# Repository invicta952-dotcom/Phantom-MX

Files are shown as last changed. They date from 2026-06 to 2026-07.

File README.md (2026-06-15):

# Phantom-MX

##   what is this??
Phantom-mx is cutom made keyboard with 87 mechincal switches, roatary encoder and custom built case and qmk firmware. It has 2 layer of functions to switch between as per your need. the case type is integrated plate mount which mean you dont need to lock the plate with case with 1000's of screw

---
##   why phantom-mx??
you may find many other custom keyboard with more features and better than this, but the one thing you will never find is perfect keyboard which is in budget and also meet your needs perfectly. it was built to meet my needs and also in budget. 
<br>
**bonus point**:- it has some really cool silkscreen

---
##   how to assemble it??
### 1. Ordering the PCB
1. **Download Production Files**: Navigate to the `PCB/` directory in this repository and download the Gerber zip file (e.g., `Gerber_Phantom-MX.zip`). Do not extract it.
2. **Choose a Manufacturer**: Upload the zip file to a PCB fabrication service such as JLCPCB, PCBWay, or OSH Park.
3. **Configure Board Settings**: Use the following standard specifications:
   * **Layers**: 2 Layers
   * **Thickness**: 1.6 mm
   * **Surface Finish**: HASL (or ENIG for better pad durability)
4. **Assembly (Optional)**: If you prefer factory assembly for surface-mount components (diodes/sockets), upload the BOM (Bill of Materials) and CPL (Component Placement List / Centroid file) provided in the repository to their PCBA service.

---

### 3. Hardware Assembly
1. **Solder Diodes**: Always solder small, low-profile components first. solder the diodes before the swithces for easy soldering.
2. **Solder Sockets/Switches**: solder the switches by passing them from top plate and then top layer of pcb.
3. **Mount the Pi Pico**: Place the Pi Pico onto its designated footprint. solder it in backside of the pcb.

---
# Images

#   case
Screenshot From 2026-06-04 00-17-47

---

#   zine
mechincal keyboard

---

#   pcb
Screenshot From 2026-06-04 00-14-03
Screenshot From 2026-05-25 17-31-20
<br>
<br>
<br>
onshape link <br>
https://cad.onshape.com/documents/175f6b23ffbe170e5e8f7975/w/d68c6b2354c565e22789bc76/e/012a72f814c196a96be20986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

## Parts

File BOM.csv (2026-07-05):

Id. | Footprint | Quantity | price | link
1 | DIODE | 88 | $1.50 | https://robu.in/product/1n4148-1w-zener-diode-pack-of-50/
2 | SW_Cherry_MX | 87 | $32.00 | https://neomacro.in/products/cherry-mx2a-linear-switch?variant=49109795701014
5 | RotaryEncoder_Alps_EC11E-Switch_Vertical_H20mm | 1 | $1.00 | https://robu.in/product/hongyan-ec11h-7ce20p1zy20-rotary-encoder-with-push-button-switch-vertical-plug-in-5-pin/
6 | RaspberryPi_Pico | 1 | $4.50 | https://robu.in/product/raspberry-pi-pico/
7 | stablizer | 1 | $10.00 | https://neomacro.in/products/tx-stabilizers-rev-3?variant=47932019474710&country=IN&currency=INR
8 | pcb | 1 | $35.00
9 | soldering iron | 1 | $10.00
10 | keycaps | 1 | $10.00
 |  | total | $105.00

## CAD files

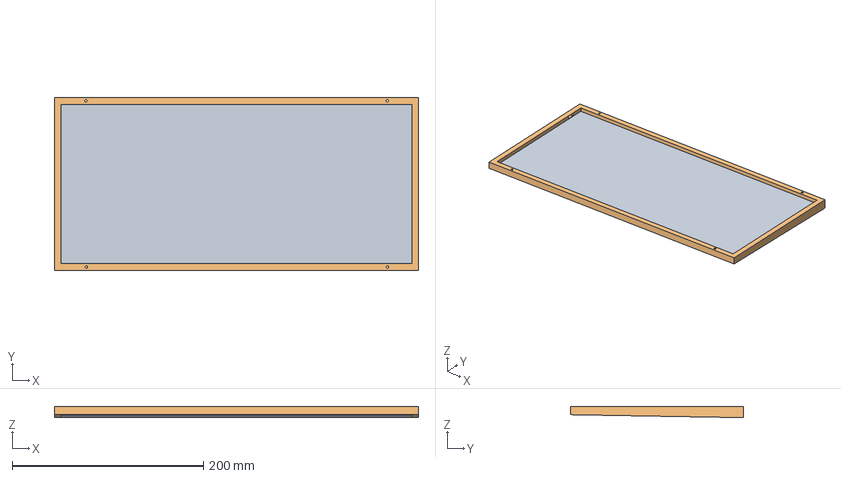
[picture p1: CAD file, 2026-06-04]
CASE/bottom.step
380.9 x 180.7 x 11.7 mm

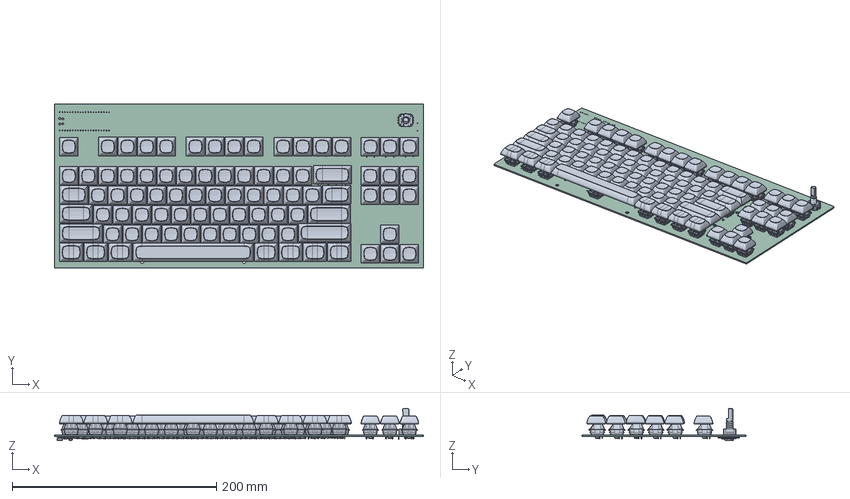
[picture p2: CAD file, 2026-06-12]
PCB/keyborad.step
360.9 x 160.7 x 31.5 mm
MX1A-C1NN--3DModel-STEP-510211 x 87
MX Mount v1 x 72
DSA 1.75u
DSA 1.25u x 7
DSA 2.75u
DSA 2.25u x 2
DSA 1.5u x 2
DSA 2u
DSA Spacebar 6.25u (50mm spacing)
RaspberryPi_Pico_Module_KiCad
keyborad_PCB

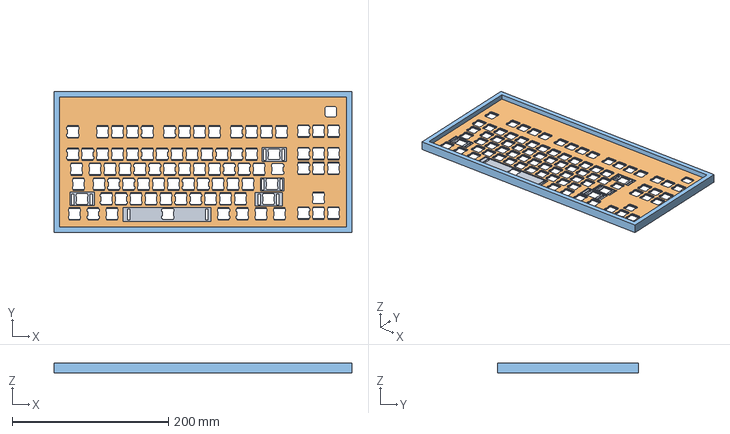
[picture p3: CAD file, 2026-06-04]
CASE/top.step
380.9 x 180.7 x 12.3 mm

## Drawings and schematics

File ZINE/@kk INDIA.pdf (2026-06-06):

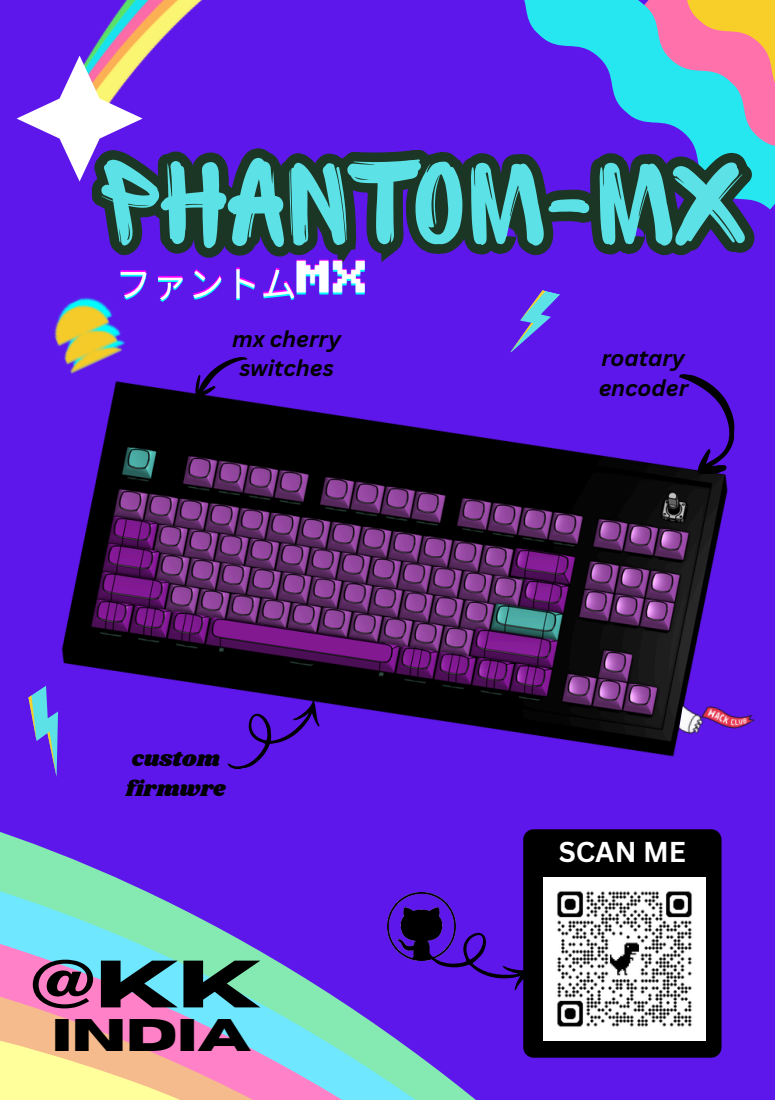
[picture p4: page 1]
@kk INDIA; SCAN ME PPHHAANNTTOOMM--MMXX; roatary encoder; custom firmwre; フファァンントトムムMMXX; mx cherry switches

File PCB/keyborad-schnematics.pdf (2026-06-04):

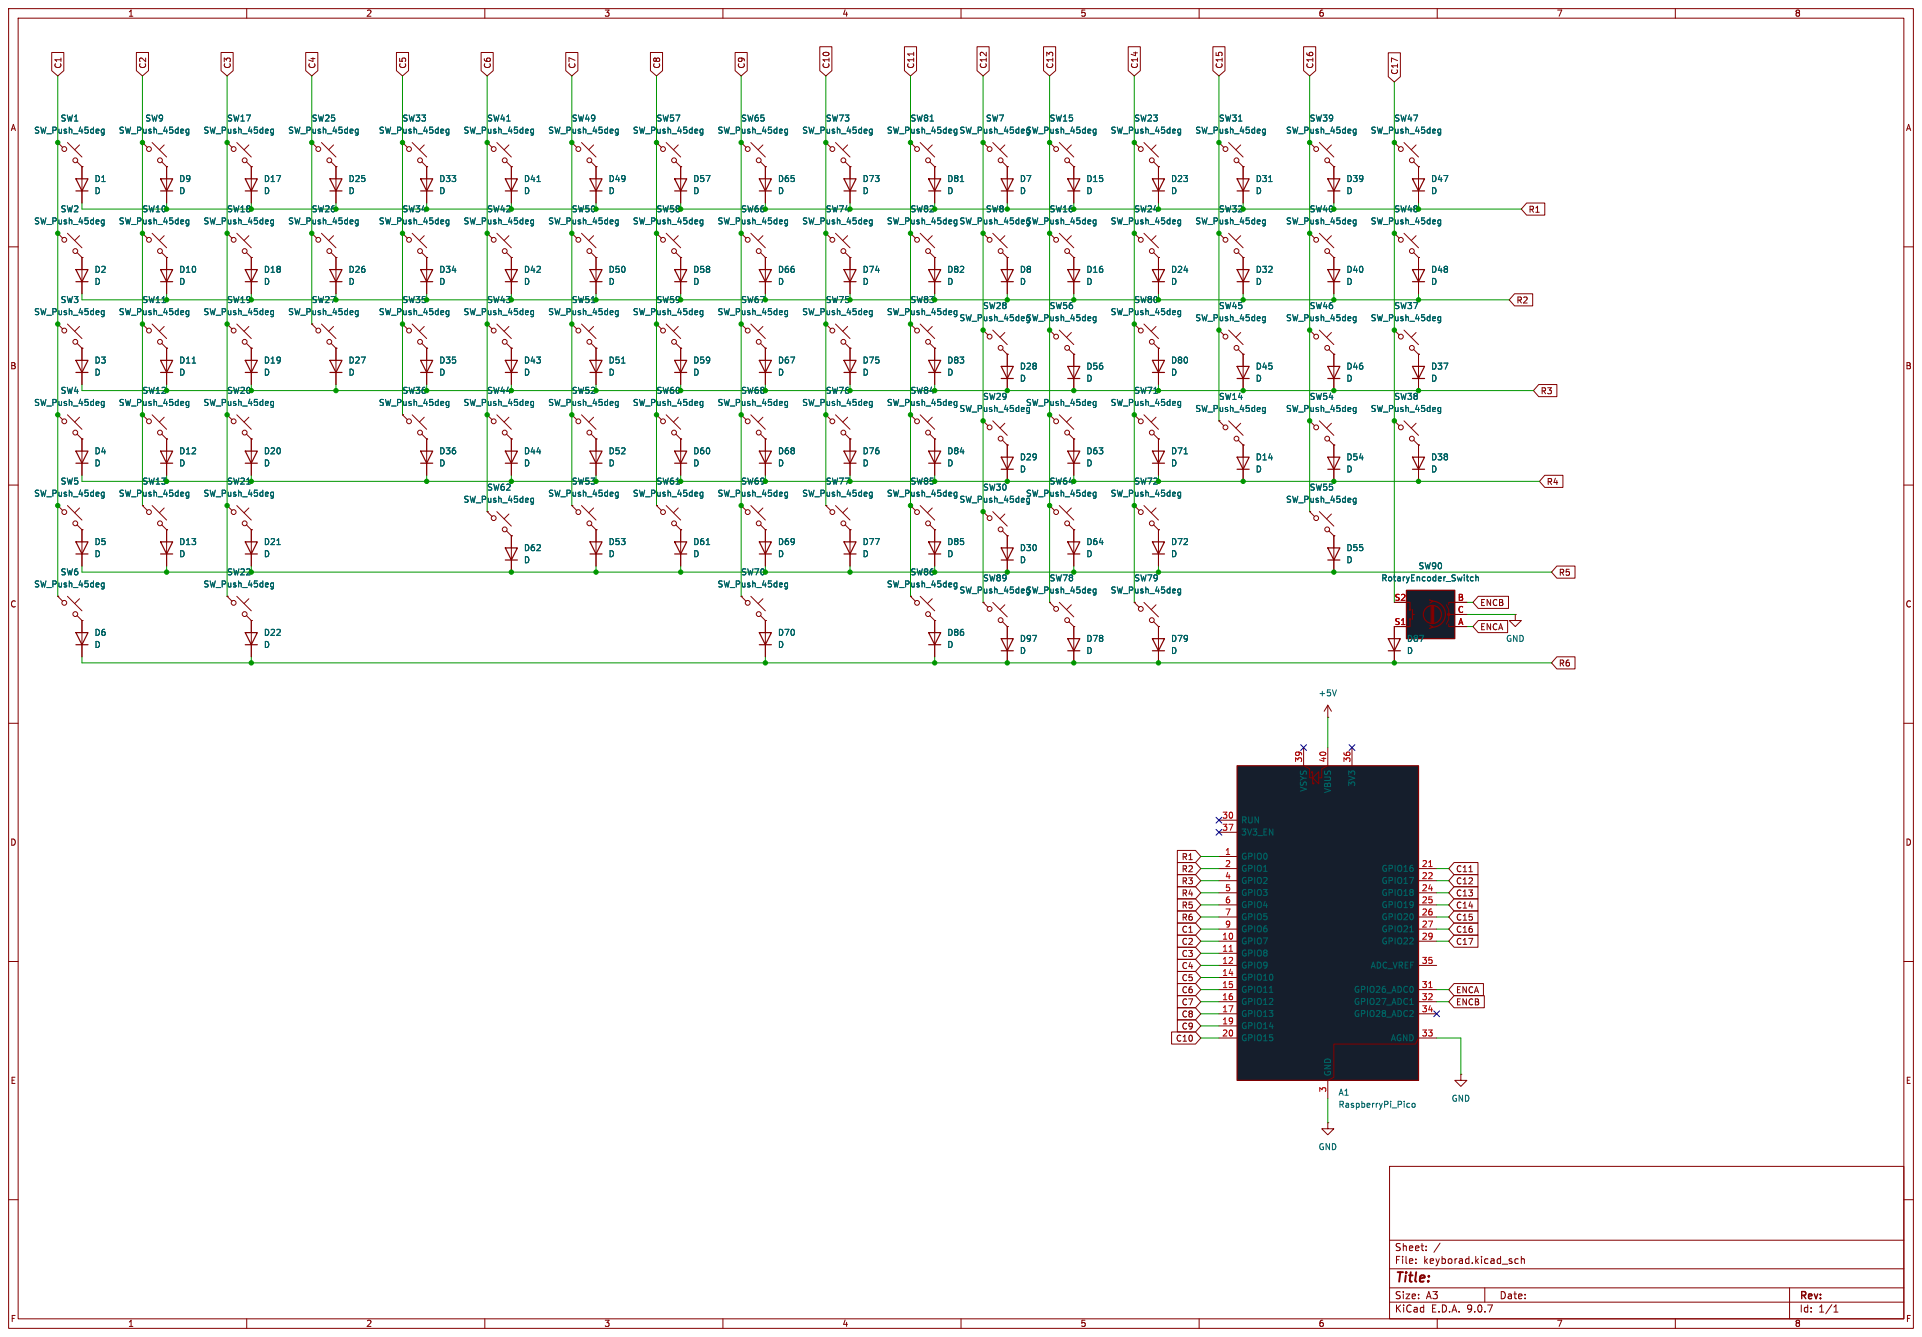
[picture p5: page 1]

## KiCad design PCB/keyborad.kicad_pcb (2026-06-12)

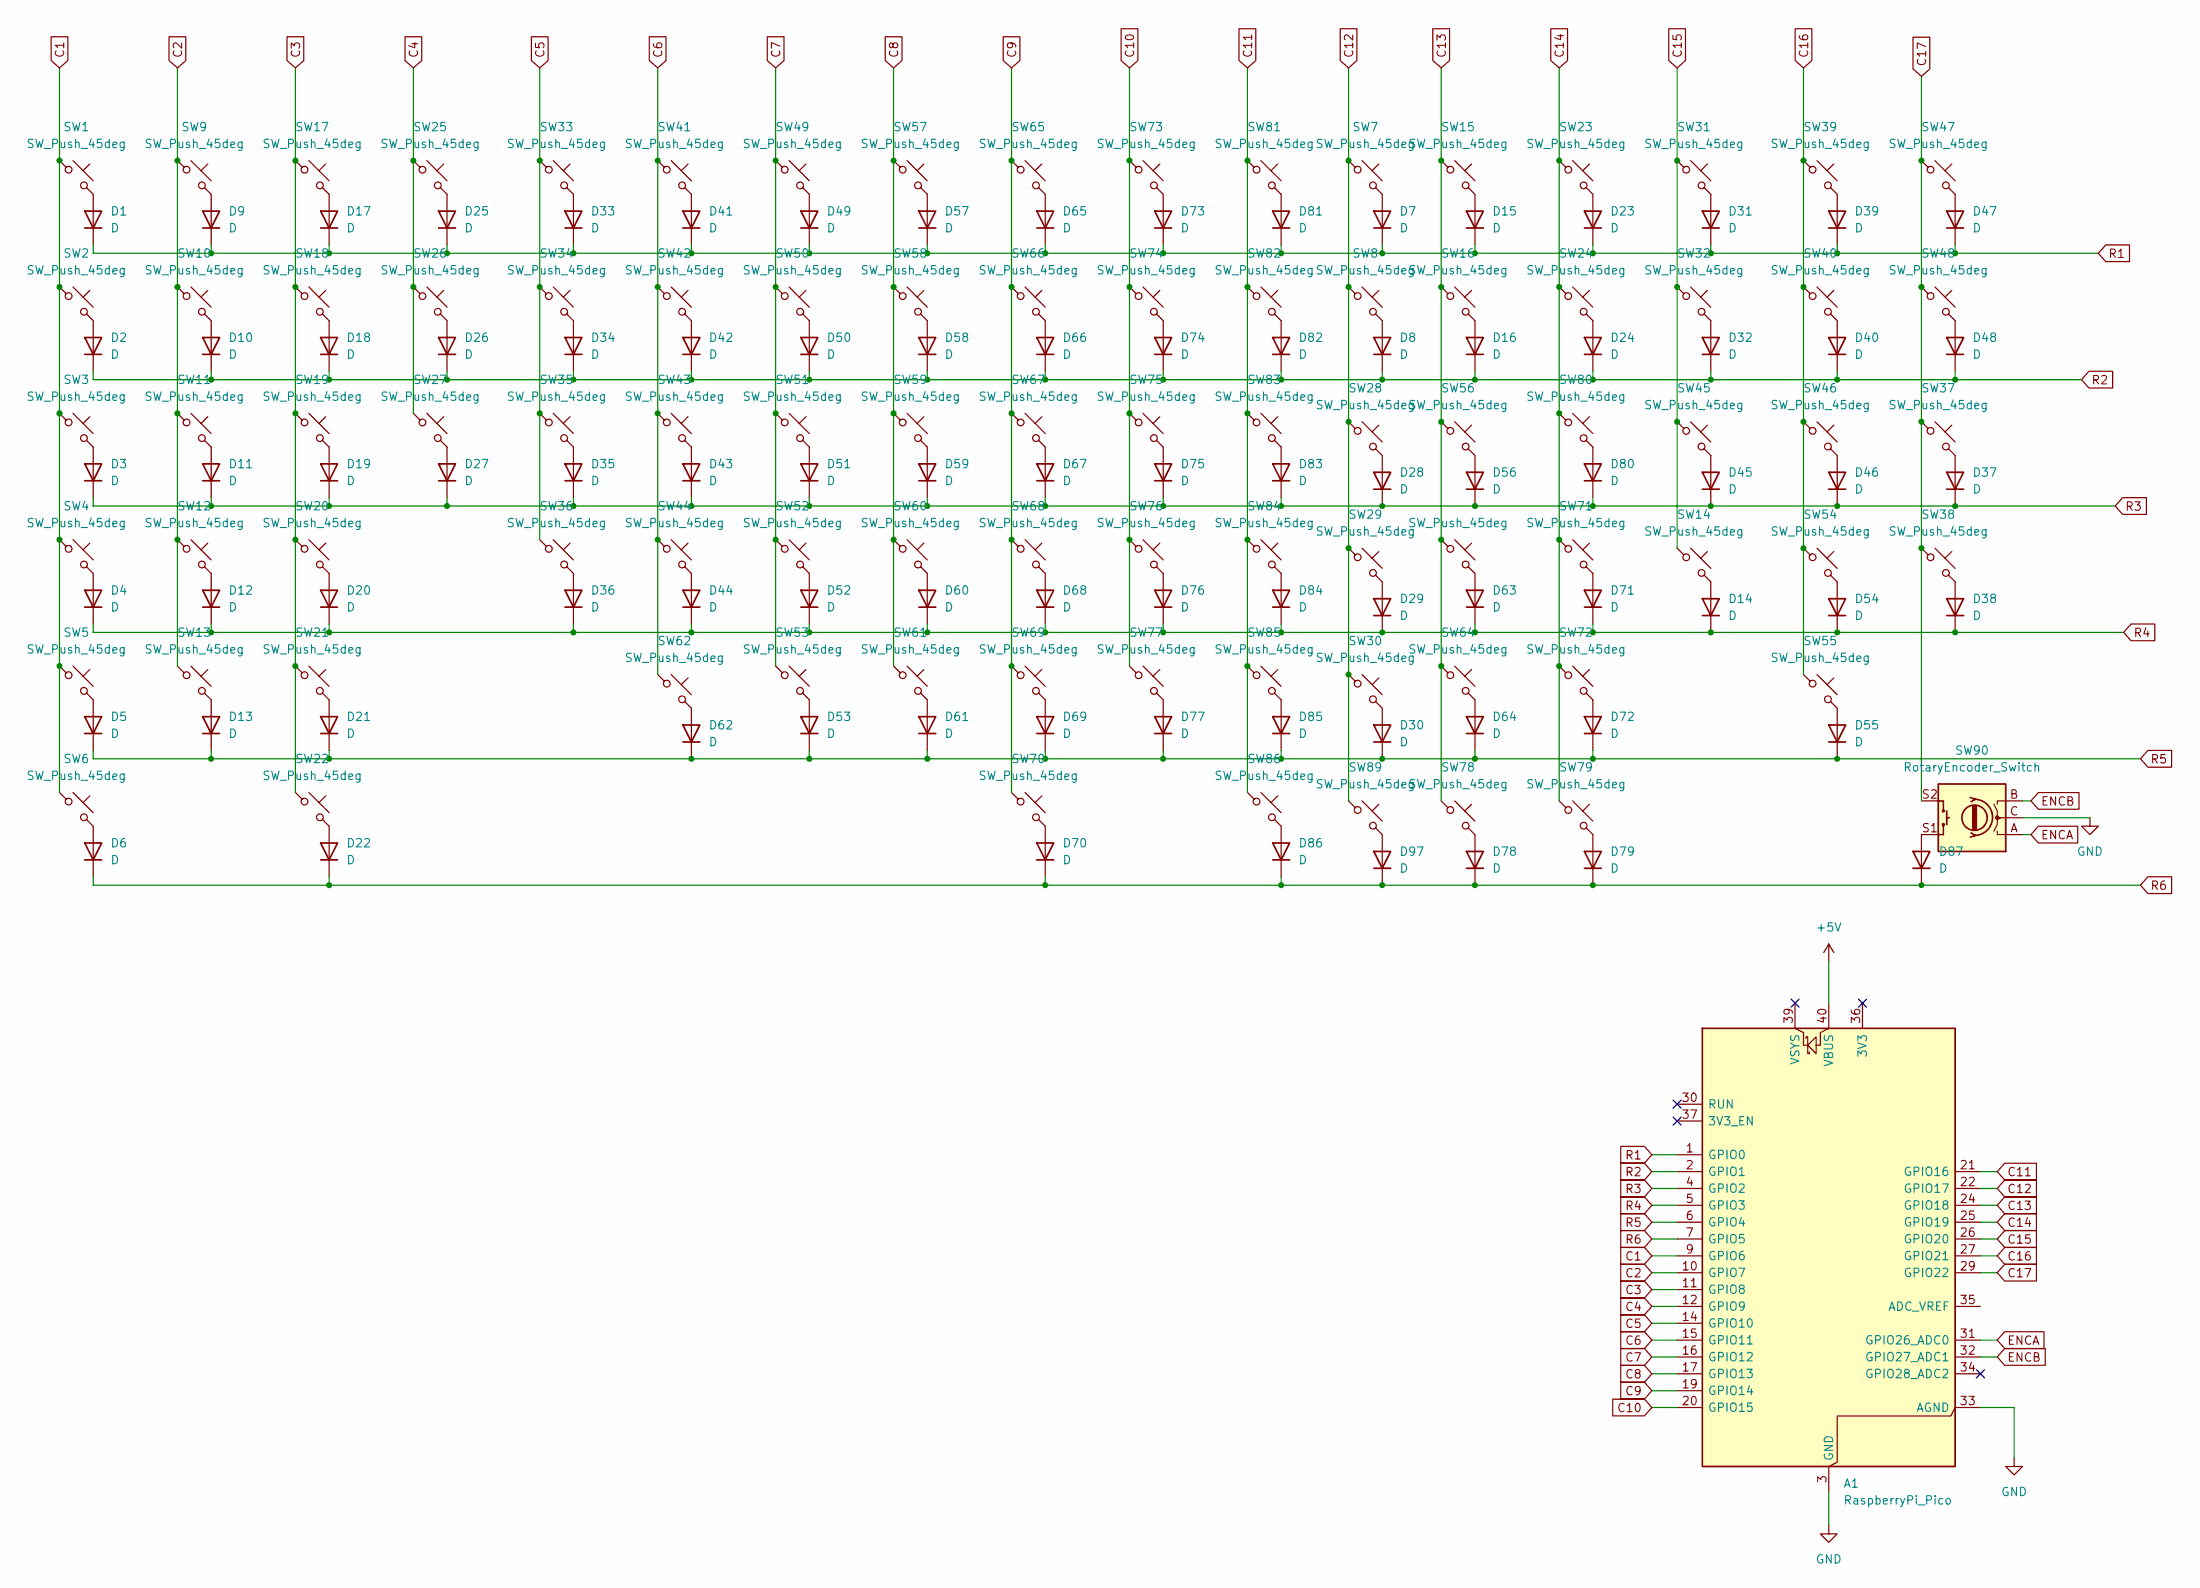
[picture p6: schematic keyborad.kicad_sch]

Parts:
A1: RaspberryPi_Pico; RaspberryPi_Pico_Common_Unspecified
D1, D2, D3, D4, D5, D6, D7, D8, D9, D10, D11, D12, D13, D14, D15, D16, D17, D18, D19, D20, D21, D22, D23, D24, D25, D26, D27, D28, D29, D30, D31, D32, D33, D34, D35, D36, D37, D38, D39, D40, D41, D42, D43, D44, D45, D46, D47, D48, D49, D50, D51, D52, D53, D54, D55, D56, D57, D58, D59, D60, D61, D62, D63, D64, D65, D66, D67, D68, D69, D70, D71, D72, D73, D74, D75, D76, D77, D78, D79, D80, D81, D82, D83, D84, D85, D86, D87, D97: D; DIODE
SW1, SW2, SW7, SW8, SW9, SW10, SW11, SW12, SW14, SW15, SW16, SW17, SW18, SW19, SW20, SW21, SW23, SW25, SW26, SW27, SW28, SW29, SW30, SW31, SW32, SW33, SW34, SW35, SW36, SW37, SW38, SW39, SW40, SW41, SW42, SW43, SW44, SW45, SW46, SW47, SW48, SW49, SW50, SW51, SW52, SW53, SW54, SW55, SW56, SW57, SW58, SW59, SW60, SW61, SW62, SW63, SW64, SW65, SW66, SW67, SW68, SW69, SW73, SW74, SW75, SW76, SW77, SW81, SW82, SW83, SW84, SW85: SW_Push_45deg; SW_Cherry_MX_1.00u_PCB
SW3, SW80: SW_Push_45deg; SW_Cherry_MX_1.50u_PCB
SW4: SW_Push_45deg; SW_Cherry_MX_1.75u_PCB
SW5, SW71: SW_Push_45deg; SW_Cherry_MX_2.25u_PCB
SW6, SW13, SW22, SW78, SW79, SW86, SW89: SW_Push_45deg; SW_Cherry_MX_1.25u_PCB
SW24: SW_Push_45deg; SW_Cherry_MX_2.00u_PCB
SW70: SW_Push_45deg; SW_Cherry_MX_6.25u_PCB
SW72: SW_Push_45deg; SW_Cherry_MX_2.75u_PCB
SW90: RotaryEncoder_Switch; RotaryEncoder_Alps_EC11E-Switch_Vertical_H20mm

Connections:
+5V: A1.40 (VBUS)
C1: A1.9 (GPIO6), SW1.1, SW2.1, SW3.1, SW4.1, SW5.1, SW6.1
C2: A1.10 (GPIO7), SW9.1, SW10.1, SW11.1, SW12.1, SW13.1
C3: A1.11 (GPIO8), SW17.1, SW18.1, SW19.1, SW20.1, SW21.1, SW22.1
C4: A1.12 (GPIO9), SW25.1, SW26.1, SW27.1
C5: A1.14 (GPIO10), SW33.1, SW34.1, SW35.1, SW36.1
C6: A1.15 (GPIO11), SW41.1, SW42.1, SW43.1, SW44.1, SW62.1
C7: A1.16 (GPIO12), SW49.1, SW50.1, SW51.1, SW52.1, SW53.1
C8: A1.17 (GPIO13), SW57.1, SW58.1, SW59.1, SW60.1, SW61.1
C9: A1.19 (GPIO14), SW65.1, SW66.1, SW67.1, SW68.1, SW69.1, SW70.1
C10: A1.20 (GPIO15), SW73.1, SW74.1, SW75.1, SW76.1, SW77.1
C11: A1.21 (GPIO16), SW81.1, SW82.1, SW83.1, SW84.1, SW85.1, SW86.1
C12: A1.22 (GPIO17), SW7.1, SW8.1, SW28.1, SW29.1, SW30.1, SW89.1
C13: A1.24 (GPIO18), SW15.1, SW16.1, SW56.1, SW63.1, SW64.1, SW78.1
C14: A1.25 (GPIO19), SW23.1, SW24.1, SW71.1, SW72.1, SW79.1, SW80.1
C15: A1.26 (GPIO20), SW14.1, SW31.1, SW32.1, SW45.1
C16: A1.27 (GPIO21), SW39.1, SW40.1, SW46.1, SW54.1, SW55.1
C17: A1.29 (GPIO22), SW37.1, SW38.1, SW47.1, SW48.1, SW90.S2
ENCA: A1.31 (GPIO26_ADC0), SW90.A
ENCB: A1.32 (GPIO27_ADC1), SW90.B
GND: A1.3 (GND), A1.8 (GND), A1.13 (GND), A1.18 (GND), A1.23 (GND), A1.28 (GND), A1.33 (AGND), A1.38 (GND), SW90.C
unnamed: D1.2 (A), SW1.2
unnamed: D2.2 (A), SW2.2
unnamed: D3.2 (A), SW3.2
unnamed: D4.2 (A), SW4.2
unnamed: D5.2 (A), SW5.2
unnamed: D6.2 (A), SW6.2
unnamed: D7.2 (A), SW7.2
unnamed: D8.2 (A), SW8.2
unnamed: D9.2 (A), SW9.2
unnamed: D10.2 (A), SW10.2
unnamed: D11.2 (A), SW11.2
unnamed: D12.2 (A), SW12.2
unnamed: D13.2 (A), SW13.2
unnamed: D14.2 (A), SW14.2
unnamed: D15.2 (A), SW15.2
unnamed: D16.2 (A), SW16.2
unnamed: D17.2 (A), SW17.2
unnamed: D18.2 (A), SW18.2
unnamed: D19.2 (A), SW19.2
unnamed: D20.2 (A), SW20.2
unnamed: D21.2 (A), SW21.2
unnamed: D22.2 (A), SW22.2
unnamed: D23.2 (A), SW23.2
unnamed: D24.2 (A), SW24.2
unnamed: D25.2 (A), SW25.2
unnamed: D26.2 (A), SW26.2
unnamed: D27.2 (A), SW27.2
unnamed: D28.2 (A), SW28.2
unnamed: D29.2 (A), SW29.2
unnamed: D30.2 (A), SW30.2
unnamed: D31.2 (A), SW31.2
unnamed: D32.2 (A), SW32.2
unnamed: D33.2 (A), SW33.2
unnamed: D34.2 (A), SW34.2
unnamed: D35.2 (A), SW35.2
unnamed: D36.2 (A), SW36.2
unnamed: D37.2 (A), SW37.2
unnamed: D38.2 (A), SW38.2
unnamed: D39.2 (A), SW39.2
unnamed: D40.2 (A), SW40.2
unnamed: D41.2 (A), SW41.2
unnamed: D42.2 (A), SW42.2
unnamed: D43.2 (A), SW43.2
unnamed: D44.2 (A), SW44.2
unnamed: D45.2 (A), SW45.2
unnamed: D46.2 (A), SW46.2
unnamed: D47.2 (A), SW47.2
unnamed: D48.2 (A), SW48.2
unnamed: D49.2 (A), SW49.2
unnamed: D50.2 (A), SW50.2
unnamed: D51.2 (A), SW51.2
unnamed: D52.2 (A), SW52.2
unnamed: D53.2 (A), SW53.2
unnamed: D54.2 (A), SW54.2
unnamed: D55.2 (A), SW55.2
unnamed: D56.2 (A), SW56.2
unnamed: D57.2 (A), SW57.2
unnamed: D58.2 (A), SW58.2
unnamed: D59.2 (A), SW59.2
unnamed: D60.2 (A), SW60.2
unnamed: D61.2 (A), SW61.2
unnamed: D62.2 (A), SW62.2
unnamed: D63.2 (A), SW63.2
unnamed: D64.2 (A), SW64.2
unnamed: D65.2 (A), SW65.2
unnamed: D66.2 (A), SW66.2
unnamed: D67.2 (A), SW67.2
unnamed: D68.2 (A), SW68.2
unnamed: D69.2 (A), SW69.2
unnamed: D70.2 (A), SW70.2
unnamed: D71.2 (A), SW71.2
unnamed: D72.2 (A), SW72.2
unnamed: D73.2 (A), SW73.2
unnamed: D74.2 (A), SW74.2
unnamed: D75.2 (A), SW75.2
unnamed: D76.2 (A), SW76.2
unnamed: D77.2 (A), SW77.2
unnamed: D78.2 (A), SW78.2
unnamed: D79.2 (A), SW79.2
unnamed: D80.2 (A), SW80.2
unnamed: D81.2 (A), SW81.2
unnamed: D82.2 (A), SW82.2
unnamed: D83.2 (A), SW83.2
unnamed: D84.2 (A), SW84.2
unnamed: D85.2 (A), SW85.2
unnamed: D86.2 (A), SW86.2
unnamed: D87.2 (A), SW90.S1
unnamed: D97.2 (A), SW89.2
R1: A1.1 (GPIO0), D1.1 (K), D7.1 (K), D9.1 (K), D15.1 (K), D17.1 (K), D23.1 (K), D25.1 (K), D31.1 (K), D33.1 (K), D39.1 (K), D41.1 (K), D47.1 (K), D49.1 (K), D57.1 (K), D65.1 (K), D73.1 (K), D81.1 (K)
R2: A1.2 (GPIO1), D2.1 (K), D8.1 (K), D10.1 (K), D16.1 (K), D18.1 (K), D24.1 (K), D26.1 (K), D32.1 (K), D34.1 (K), D40.1 (K), D42.1 (K), D48.1 (K), D50.1 (K), D58.1 (K), D66.1 (K), D74.1 (K), D82.1 (K)
R3: A1.4 (GPIO2), D3.1 (K), D11.1 (K), D19.1 (K), D27.1 (K), D28.1 (K), D35.1 (K), D37.1 (K), D43.1 (K), D45.1 (K), D46.1 (K), D51.1 (K), D56.1 (K), D59.1 (K), D67.1 (K), D75.1 (K), D80.1 (K), D83.1 (K)
R4: A1.5 (GPIO3), D4.1 (K), D12.1 (K), D14.1 (K), D20.1 (K), D29.1 (K), D36.1 (K), D38.1 (K), D44.1 (K), D52.1 (K), D54.1 (K), D60.1 (K), D63.1 (K), D68.1 (K), D71.1 (K), D76.1 (K), D84.1 (K)
R5: A1.6 (GPIO4), D5.1 (K), D13.1 (K), D21.1 (K), D30.1 (K), D53.1 (K), D55.1 (K), D61.1 (K), D62.1 (K), D64.1 (K), D69.1 (K), D72.1 (K), D77.1 (K), D85.1 (K)
R6: A1.7 (GPIO5), D6.1 (K), D22.1 (K), D70.1 (K), D78.1 (K), D79.1 (K), D86.1 (K), D87.1 (K), D97.1 (K)

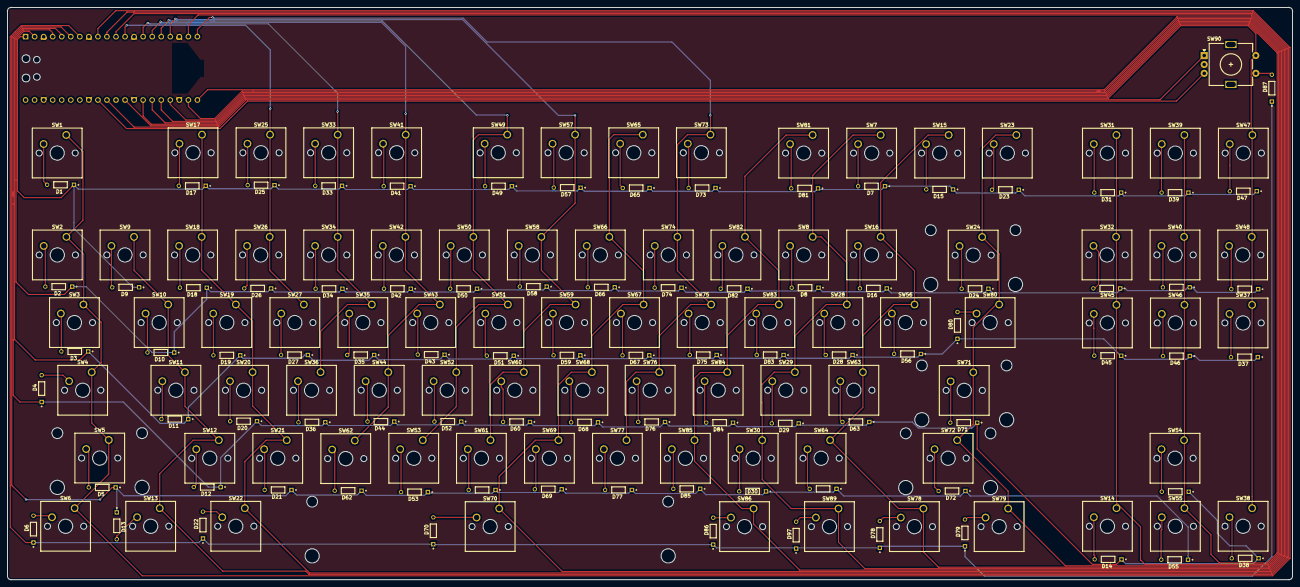
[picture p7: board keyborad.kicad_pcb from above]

Board: 2 copper layers, 360.9 x 160.7 mm, 177 parts (1 on the bottom side), 114 nets.

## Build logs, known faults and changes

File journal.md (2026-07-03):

# Phantom-MX — Journal Export

- Exported at: 2026-06-20T15:56:06Z
- Project ID: 2269
- Entries: 10

## Entry 1
- ID: 2750
- Author: KK
- Created At: 2026-04-18

### Content

things i did in this lapse:-
1) did the layout of the keyboard

i first wanted it to be somewhat like mac layout but then halfway there i reaslied that i wouldnt get keycaps for mac layout. i want it to rgb foe every key.

this is what i desgined till now <br>


**Total time spent: 35min**

### Recording Links

- https://public.lapse-hackclub.link/timelapses/zlmdRCJbs8y6/timelapse-zlmdRCJbs8y6.mp4

## Entry 2
- ID: 2927
- Author: KK
- Created At: 2026-04-19

### Content

things i did in this lapse:-
1) did the matrics of the keyboard.

problems:-
didnt really faced any problems. it was just time consuming but also easy at same time. i later realised that i should have done one row and then copy paste it.

anyway this is result of my work <br>


**Total time spent: 1h 4min**

### Recording Links

- https://public.lapse-hackclub.link/timelapses/gyCBLYItfm7b/timelapse-gyCBLYItfm7b.mp4
- https://public.lapse-hackclub.link/timelapses/5noOYQI94lu7/timelapse-5noOYQI94lu7.mp4
- https://public.lapse-hackclub.link/timelapses/EL8UGGkxV7zc/timelapse-EL8UGGkxV7zc.mp4
- https://public.lapse-hackclub.link/timelapses/eyvg1s67Wnu2/timelapse-eyvg1s67Wnu2.mp4

## Entry 3
- ID: 3084
- Author: KK
- Created At: 2026-04-20

### Content

things i did in this lapse:-
1) added usb
2) rgb backligth

problem:-
i wanted to add few rgb backlight but they needed more amp than i could pass through the pico so i needed to add seperate usb c for it.

final schnematics of usb-c <br>
 <br>

p.s. i am writting this journal 1 min before streak deadline

**Total time spent: 1h 1min**

### Recording Links

- https://public.lapse-hackclub.link/timelapses/OuZXTdKR3aUO/timelapse-OuZXTdKR3aUO.mp4
- https://public.lapse-hackclub.link/timelapses/qdg6aQ4NelVP/timelapse-qdg6aQ4NelVP.mp4

## Entry 4
- ID: 3250
- Author: KK
- Created At: 2026-04-21

### Content

things i did in this lapse:-
1) added neo rgb for backglow
2) assigned the footprints

and yeah also i will make the keys hotswappable

problems:-
the problem i faced was just that i didnt knew which footprint i need to use for each compnent and its solutions is just google it. yeah, most of problems u have can be solved just by google it.
extra tip:- when googleing something always look for reedit

somewhat of inspiration <br>
 <br>

schnematics of rgb <br>

 <br>

**Total time spent: 1h 4min**

### Recording Links

- https://public.lapse-hackclub.link/timelapses/b7qrX8xc4CLV/timelapse-b7qrX8xc4CLV.mp4
- https://public.lapse-hackclub.link/timelapses/GxKIIjKD6gCp/timelapse-GxKIIjKD6gCp.mp4

## Entry 5
- ID: 3429
- Author: KK
- Created At: 2026-04-22

### Content

things i did in this lapse:-
1) completed the layout

problems:-
i think i have messed up. i am one key short than my layout of keyboard. i dont think it will be much of problem. lets see what happens. and i didnt have any major problem expect i didnt know how long is space bar and other long keys

final layout


the red lines i made for reffrence

**Total time spent: 1h 1min**

### Recording Links

- https://public.lapse-hackclub.link/timelapses/unkwQeibfS_Y/timelapse-unkwQeibfS_Y.mp4
- https://public.lapse-hackclub.link/timelapses/8OkCZsIDnVaw/timelapse-8OkCZsIDnVaw.mp4
- https://public.lapse-hackclub.link/timelapses/WslslfNCwh3S/timelapse-WslslfNCwh3S.mp4

## Entry 6
- ID: 6784
- Author: KK
- Created At: 2026-05-12
### Content

### **_OKAY I REALLY FUCKED UP_**
the thing is i made the matrix correctly in the keyboard jpg but in schnematics i just made an square matix. i didnt really understand about it until i was about to start routing that time i realised that it was just a big mess. then i solved it by doing the matrix in schnematics acc to the one i orginally decided

before


after


also i recommend everyone to switch to dark mode

and another thing i tried using the autoplacer but it didnt quite get the switches right like space bar. so i had to manually place every key


**Total time spent: 4h 16min**

### Recording Links

- https://public.lapse-hackclub.link/timelapses/NtLez9SaRGXM/timelapse-NtLez9SaRGXM.mp4
- https://public.lapse-hackclub.link/timelapses/AVqJip1clJZb/timelapse-AVqJip1clJZb.mp4
- https://public.lapse-hackclub.link/timelapses/smnLaAT01Y7L/timelapse-smnLaAT01Y7L.mp4
- https://public.lapse-hackclub.link/timelapses/MYx493U7_ChA/timelapse-MYx493U7_ChA.mp4
- https://public.lapse-hackclub.link/timelapses/vJk5HcyJw8JK/timelapse-vJk5HcyJw8JK.mp4
- https://public.lapse-hackclub.link/timelapses/fxKx1orKj46l/timelapse-fxKx1orKj46l.mp4
- https://public.lapse-hackclub.link/timelapses/pA0BS6PRpUOM/timelapse-pA0BS6PRpUOM.mp4
- https://public.lapse-hackclub.link/timelapses/-mMSg2skFTXq/timelapse--mMSg2skFTXq.mp4
- https://public.lapse-hackclub.link/timelapses/QzkJIQGgtqW0/timelapse-QzkJIQGgtqW0.mp4

## Entry 7
- ID: 7132
- Author: KK
- Created At: 2026-05-14

### Content

### **_the routing is finally completed_**

so the routing is completed and it looks really cool and clean as per my standard. the whole process went really well i didnt had any problem. 

for anyone reading my journal what u should do when routing a keyboard is when going horizontal use backside and when going vetical use front side to route.


also i didnt mention it in previous journal but i have removed the rgb lights for backglow cuz i didnt have any gipo pins left

**Total time spent: 2h 47min**

### Recording Links

- https://public.lapse-hackclub.link/timelapses/XLDYGO7PHQGZ/timelapse-XLDYGO7PHQGZ.mp4
- https://public.lapse-hackclub.link/timelapses/px6Y4y_rcfOn/timelapse-px6Y4y_rcfOn.mp4
- https://public.lapse-hackclub.link/timelapses/nIrz0ltbxj95/timelapse-nIrz0ltbxj95.mp4
- https://public.lapse-hackclub.link/timelapses/xCwwrQ9rE1rD/timelapse-xCwwrQ9rE1rD.mp4

## Entry 8
- ID: 9092
- Author: KK
- Created At: 2026-05-25

### Content

### _Note for reviewer_
the lapse with name "error and correction" is actually of 48 min but somehow ended up of 1hr 21min.

things i did in the lapse:-
1. desgined the plate
2. brought the pcb in 3d
3. realised it wayyyyy big
4. made it compact
5. added 3d model of switches

when i first added the pcb i realised that it is bigger than i thought. then i removed all the unnesscary parts like seperate usb-c port as pi pico has one built-in. also first i thought of sandwich style but then realised that integrated plate mount is just better. and yeah when i assiging the 3d model i reaslied that pi pico is inveted but it was too late to change so i just went with it.

3D MODEL THAT WENT TO WASTE


ROUTING


3D MODEL OF PCB


**Total time spent: 6h 46min**

### Recording Links

- https://public.lapse-hackclub.link/timelapses/kU6G1z5ZEjZr/timelapse-kU6G1z5ZEjZr.mp4
- https://public.lapse-hackclub.link/timelapses/IhdCssehZ4Nl/timelapse-IhdCssehZ4Nl.mp4
- https://public.lapse-hackclub.link/timelapses/c9N1vuwW96u5/timelapse-c9N1vuwW96u5.mp4
- https://public.lapse-hackclub.link/timelapses/DURTy7pOsrnm/timelapse-DURTy7pOsrnm.mp4
- https://public.lapse-hackclub.link/timelapses/kLBslB7lZfx2/timelapse-kLBslB7lZfx2.mp4
- https://public.lapse-hackclub.link/timelapses/VY8dAnxNtfFW/timelapse-VY8dAnxNtfFW.mp4
- https://public.lapse-hackclub.link/timelapses/m4crFCDKRbCH/timelapse-m4crFCDKRbCH.mp4

## Entry 9
- ID: 11440
- Author: KK
- Created At: 2026-06-03
### Content

lets start lapse by lapse so the journal could be detailed enough

### **"almost complete with pcb"**
in this lapse i rendered the step file of all the keycaps. the normal 1u ones i updated it to universal 3d model and for the others like 1.5u, 2u etc i did all of them manually as there were only few of them. For the 6u one i intially didnt find the step file in the repo so i had to search for it. i put the keycaps at the same height so i can see symmetry over the pcb.

### "CAD"
in this lapse i started with the cad. i dont know why but i couldnt bring the pcb to he centre. i even tried it offscreen yet couldnt do it. my best guess is due to huge number of components. also onshape exports all the componets in random colour so i have to select all the componets indivaully and set the colour. other than that i made the wall and the plate for case. i am going with integrated plate mount and mx cherry stablizers with 5 pin mx cherry key switch. i couldnt find the model for 5 pin so i just used 3pin for now.

### **"CAD-2"**
made few changes to plate. made a hole of rotarty encoder as i forgot to make one earlier and also made the bottom part of the case. 

### "CAD ALMOST OVER"
in this lapse i completed the plate. made another thing below the plate to use it as support between pcb and plate. took out 1mm from sides of space which  was for the switches to account for printing tolerance. for the stablizers. i just removed a rectangle instead of making it so it perfectly fits. i also tried to make small legs at the bottom so it dont just slides

### "Finshing touch"
in this lapse i changed the colour of the mx cherry to black so  it matches the colour therme. also i just jot rid of the legs which i couldnt make using revole. i even watched some tutorials. instead of that i am going with curved botttom so the front part is lower compared to back side but in this lapse i did the complete opposite and made front part higher. also made some really cool colour theme with purple colour.

**"github"**
it is not what it sounds like. i  started the lapse with intention to start making the repo but in between i realised that i didnt add any silkscreen in the pcb and i also rounded the corners of the pcb which i intially forgoted.

### "assemblly"
i fixed the slope so now it is lower at front side. i forgot the main thing about integrated plate mount 'the screws'. yeah, i totally forgot the screw. i added the hole for heat insert. i am going to use m2 screws for it. i assembled everything in assembly. for the heat insert i used this formula
                                  **holes diameter=outer diameter of heat insert-0.4mm**

i am going to dump all the screenshot at the end. sry to reviewer











**Total time spent: 5h 39min**

### Recording Links

- https://public.lapse-hackclub.link/timelapses/F7u9kfEwWhnH/timelapse-F7u9kfEwWhnH.mp4
- https://public.lapse-hackclub.link/timelapses/VArmTJahcoRM/timelapse-VArmTJahcoRM.mp4
- https://public.lapse-hackclub.link/timelapses/CPkMvHW8vwYx/timelapse-CPkMvHW8vwYx.mp4
- https://public.lapse-hackclub.link/timelapses/qURsDXvyVIJy/timelapse-qURsDXvyVIJy.mp4
- https://public.lapse-hackclub.link/timelapses/Cyu42BvWPmZD/timelapse-Cyu42BvWPmZD.mp4
- https://public.lapse-hackclub.link/timelapses/KfRpt5eacOoH/timelapse-KfRpt5eacOoH.mp4
- https://public.lapse-hackclub.link/timelapses/WyEy-WDNm_lN/timelapse-WyEy-WDNm_lN.mp4

## Entry 10
- ID: 14195
- Author: KK
- Created At: 2026-06-15
  
### Content

things i did in these lapse:-
completed the gihtub repo. i atcually worked for about 1:30 hr but i paused the recording and forgot to turn it on again. i also made the zine. the colour were very hard to find because the bg didnt match with most of colours.
now the most hardest part was firmware for me as i am not that good with software. i admit that i did used ai for that but noyt entirly. i had one big problem when i was making gihtub repo that .step file for case+keyboard was 59mb but github has a limit of 25mb so i imported using terminal. i am no expert for that so i used ai to help me. one thing, i didnt used ai with lapse on, i just paused lapse for using ai.

**ZINE**
mechincal keyboard

**Total time spent: 4h 3min**

### Recording Links

- https://public.lapse-hackclub.link/timelapses/WhL3ARhoel9M/timelapse-WhL3ARhoel9M.mp4
- https://public.lapse-hackclub.link/timelapses/QpHEBAkRnL2f/timelapse-QpHEBAkRnL2f.mp4
- https://public.lapse-hackclub.link/timelapses/c-TWY7vUWmWC/timelapse-c-TWY7vUWmWC.mp4
- https://public.lapse-hackclub.link/timelapses/eg7JvjpoXG_D/timelapse-eg7JvjpoXG_D.mp4
- https://public.lapse-hackclub.link/timelapses/d8q0rwd6JC5E/timelapse-d8q0rwd6JC5E.mp4
- https://public.lapse-hackclub.link/timelapses/Bux3aZczQwhe/timelapse-Bux3aZczQwhe.mp4

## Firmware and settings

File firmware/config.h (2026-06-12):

#pragma once

#define VENDOR_ID       0xFEED
#define PRODUCT_ID      0x0001
#define DEVICE_VER      0x0001
#define MANUFACTURER    Custom
#define PRODUCT         RP2040 Keyboard


#define MATRIX_ROWS 6
#define MATRIX_COLS 17

#define MATRIX_ROW_PINS { GP0, GP1, GP2, GP3, GP4, GP5}
#define MATRIX_COL_PINS { GP6, GP7, GP8, GP9, GP10, GP11, GP12, GP13, GP14, GP15, GP16, GP17, GP18, GP19, GP20, GP21, GP22}
#define DIODE_DIRECTION COL2ROW

#define ENCODER_A_PINS { GP26 }
#define ENCODER_B_PINS { GP27 }
#define ENCODER_RESOLUTION 4  

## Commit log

2026-06-04 Rename keyborad (1).step to bottom.step
    [bottom.step]
2026-06-13 added case.step to case
